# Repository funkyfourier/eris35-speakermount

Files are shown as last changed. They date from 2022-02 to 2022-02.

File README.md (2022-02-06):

# 3D Printable Speaker Wall Mounts for PreSonus ERIS E3.5

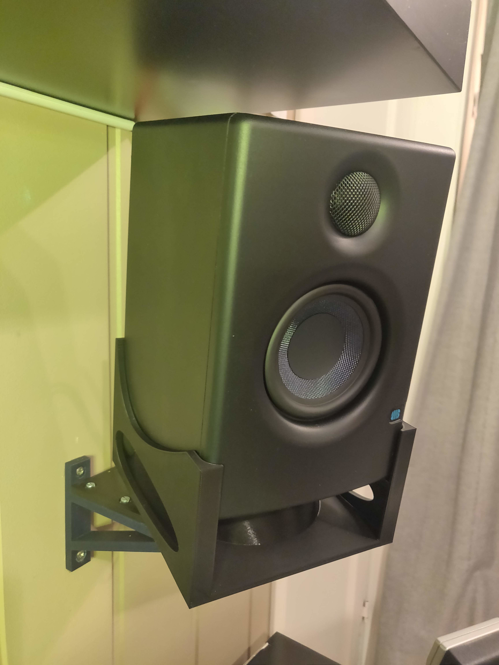
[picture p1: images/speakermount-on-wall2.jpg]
Mounted on wall with speaker


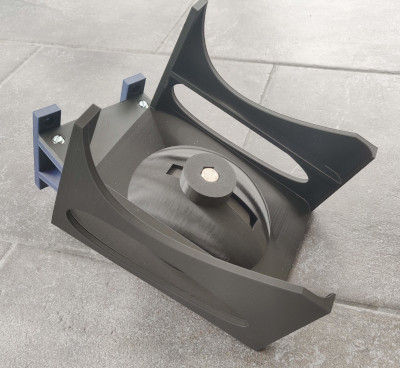
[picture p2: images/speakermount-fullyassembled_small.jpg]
Fully assembled


These are 3D printable speaker wall mounts for [the Presonus ERIS E3.5 speakers](https://www.presonus.com/products/Eris-E35). They can be tiltet and rotated to allow for optimal listening angle. 

The models are made with [FreeCAD](https://www.freecadweb.org/), and all dimensions and sizes should be possible to adjust using the spreadsheet. It may not respond 100% perfect to changes, though, so check the results after editing. Some experience with FreeCAD is recommended.

To build one of them, you will need the following items:

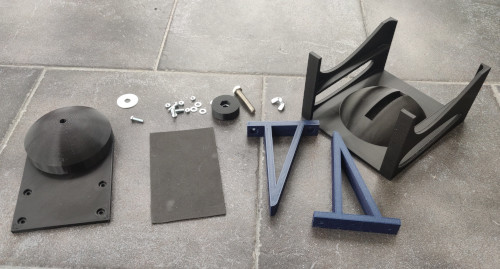
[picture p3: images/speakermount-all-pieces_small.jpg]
All pieces


* Speakerframe.stl
* Bracket.stl
* Fastener.stl
* Shelf.stl
* 4x M4 screws and nuts for mounting shelf to brackets
* 4x ~10mm washers (for M4) for mounting shelf to brackets
* 1x M8 bolted nut
* 1x M8 wing nut
* 1x 30mm washers for the wing nuts
* 2x internal 30mm washers for the fastener (optional)
* screws for mounting brackets to wall
* rubber sheet of some kind (optional)

The rubber sheet is for adding extra friction, and it is placed on top of the dome on the shelf part, with a hole cut in the center.

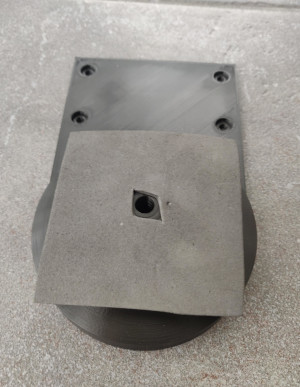
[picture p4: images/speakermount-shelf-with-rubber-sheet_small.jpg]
Rubber sheet


You can probably skip it, but I found that they reduce the need for tightening the wing nut quite a bit. I don't know where to get them, I got mine in the packaging of some product I bought.

If you have a slicer and printer which allows for color changing pauses, you can opt to insert an internal washer in the fastener. 

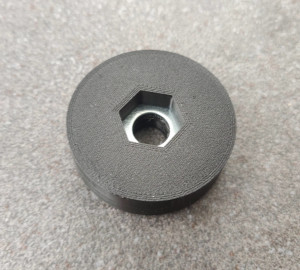
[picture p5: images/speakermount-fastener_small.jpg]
Fastener with internal washer


If you do so, I recommend to add an extra layer on top of the washer to implement sacrifical briding, as explained in [this video by Maker's Muse](https://youtu.be/RPijCjz9G1w?t=117). He does it in CAD, but I just did it directly in Prusa Slicer, although a bit cumbersome. 

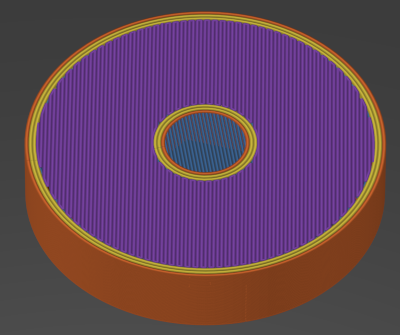
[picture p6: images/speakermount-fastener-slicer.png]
Fastener in slicer with sacrificial support


The speaker frame itself should be printed in this orientation:

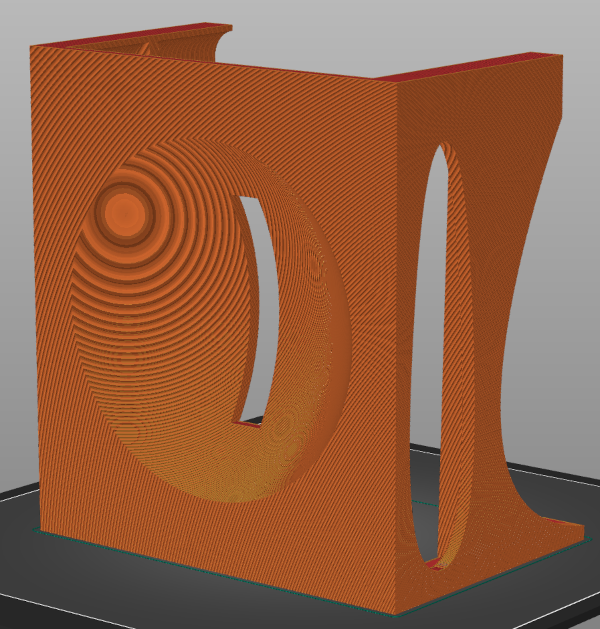
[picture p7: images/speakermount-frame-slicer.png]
Fastener in slicer with sacrificial support


No supports are needed. 

**You may want to do a couple of test prints before printing the frames, since the dimensions might be off depending on how your (and my) printer is set up and tuned.**

The shelves can be printed sideways, also without supports.

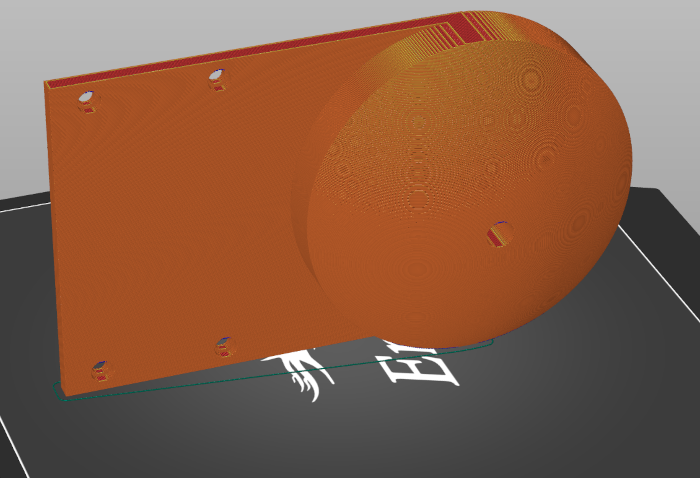
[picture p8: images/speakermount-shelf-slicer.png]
Shelf sideways in slicer


If you know a little bit about [FreeCAD](https://www.freecadweb.org/) you may adjust some of the values in the spreadsheet, like screw hole sizes etc. Also, it is fully possible to adjust the frame for many other speakers, so remix away!

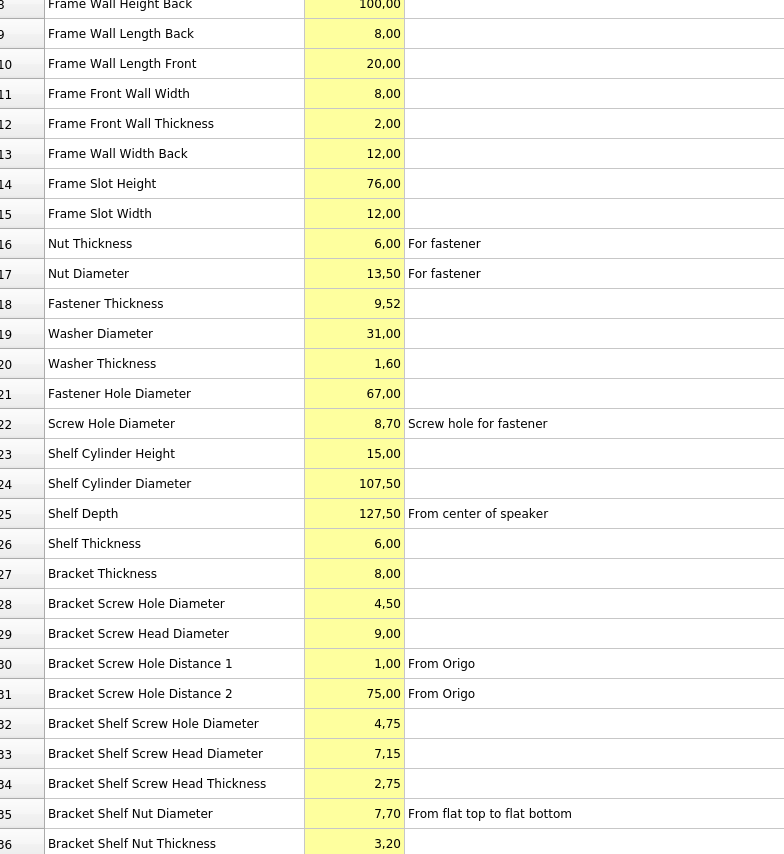
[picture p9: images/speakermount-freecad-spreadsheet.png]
FreeCAD spreadsheet


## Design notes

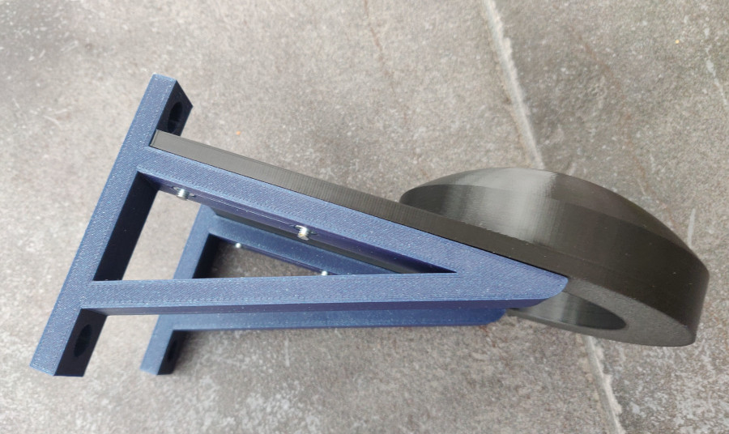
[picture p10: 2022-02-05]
images/speakermount-shelf-and-brackets.jpg

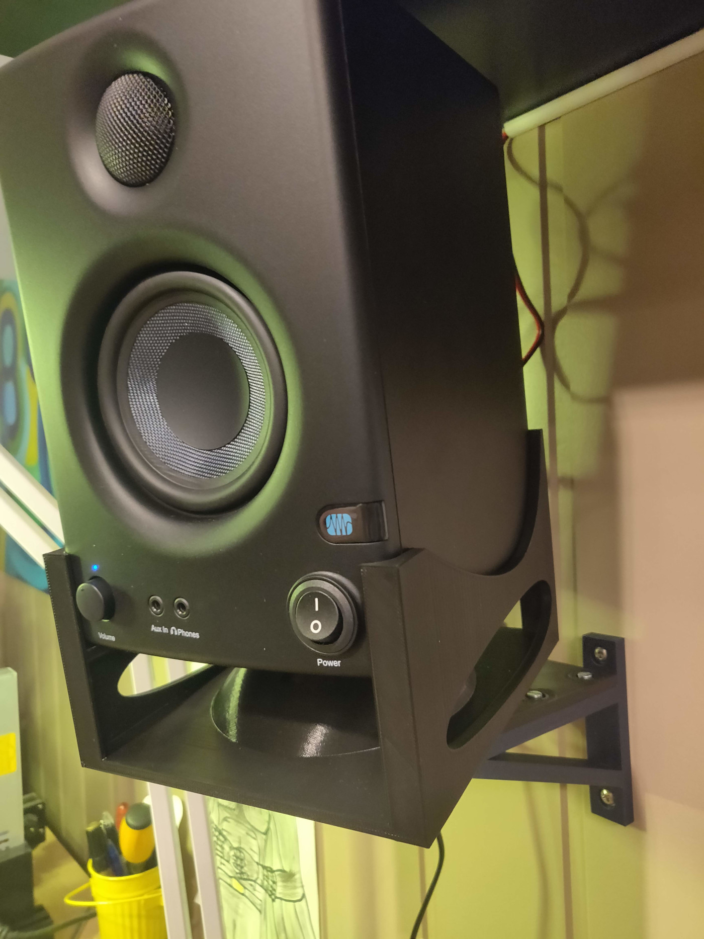
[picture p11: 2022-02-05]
images/speakermount-on-wall.jpg

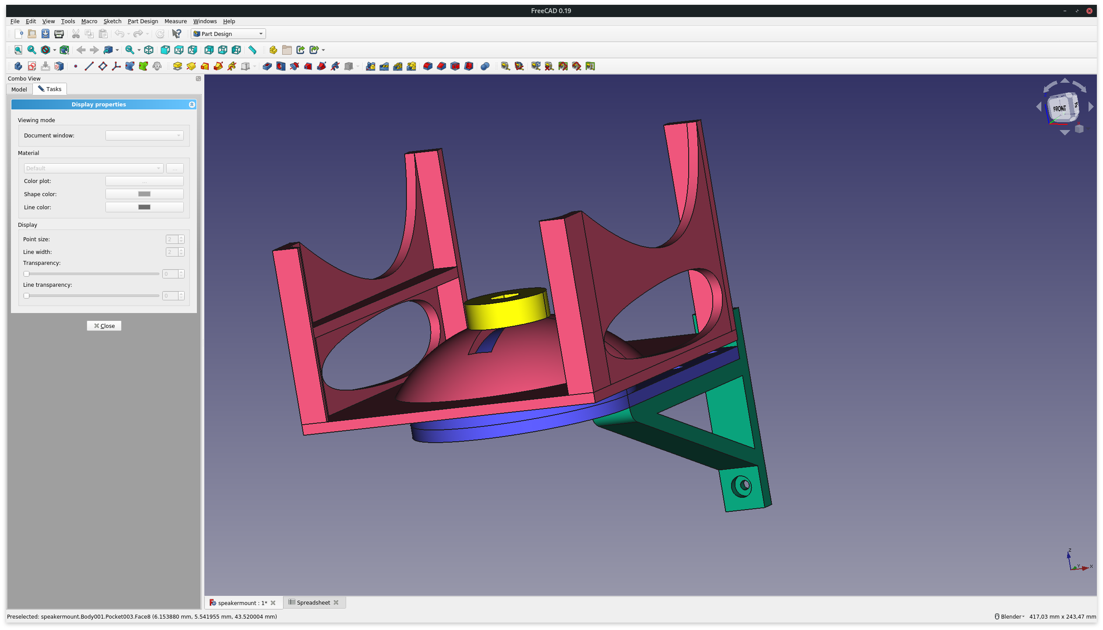
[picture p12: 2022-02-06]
images/freecad.png

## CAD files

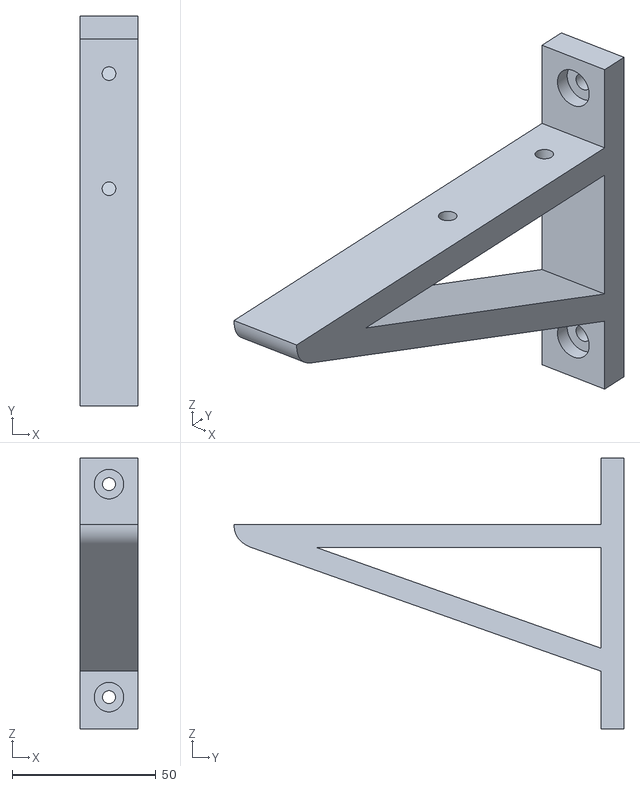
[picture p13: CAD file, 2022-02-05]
Bracket.stl
20.2 x 135.5 x 94.0

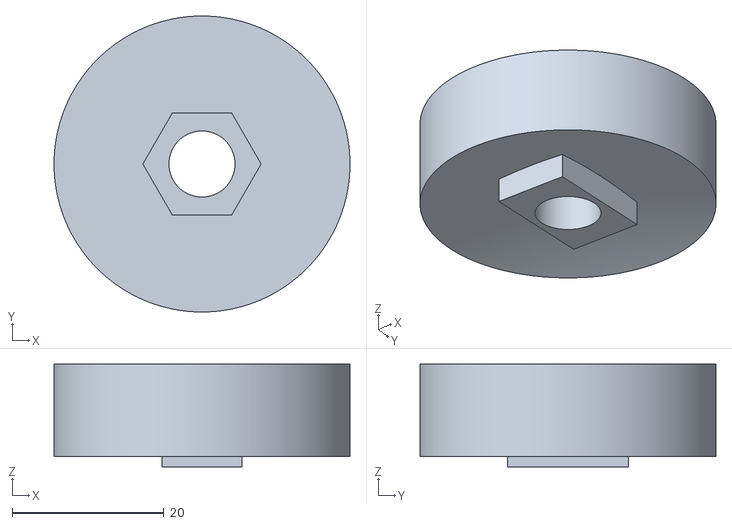
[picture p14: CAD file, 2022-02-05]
Fastener.stl
39.0 x 39.0 x 13.5

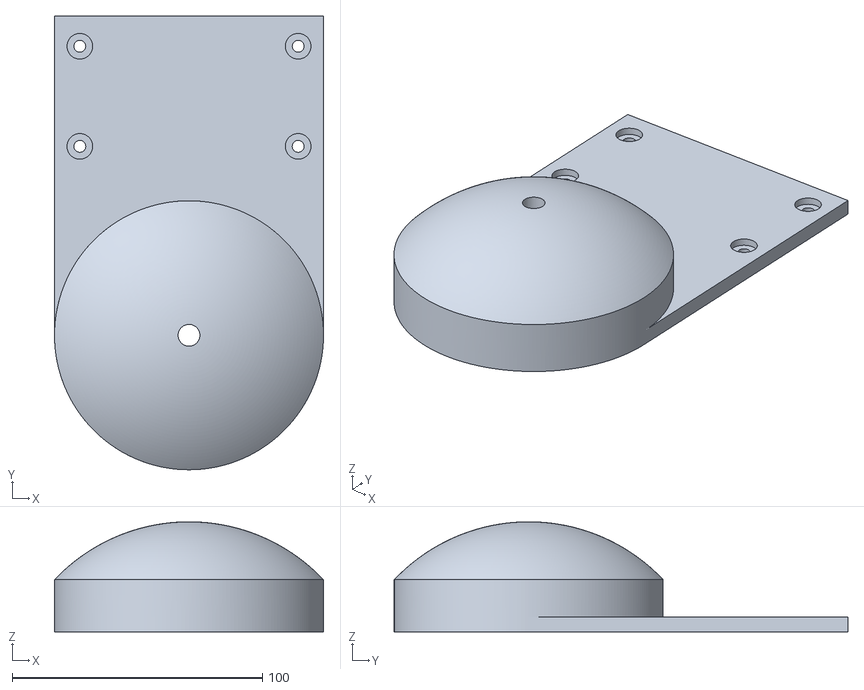
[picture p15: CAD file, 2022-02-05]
Shelf.stl
107.5 x 181.2 x 43.9

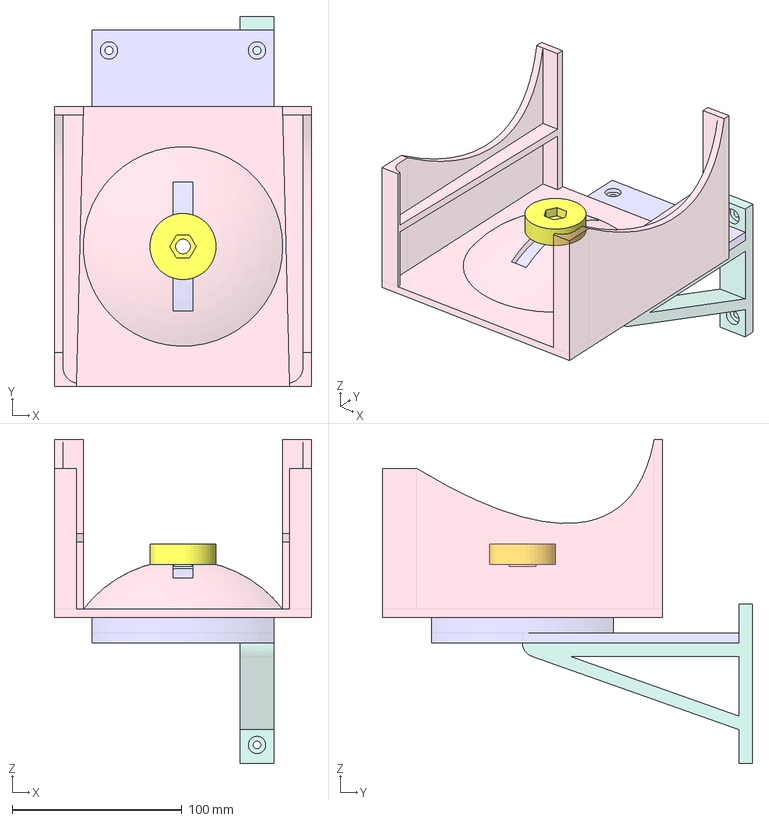
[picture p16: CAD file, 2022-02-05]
speakermount.FCStd
151.5 x 218.0 x 191.0 mm
SpeakerFrame
Fastener
Shelf
Bracket

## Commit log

2022-02-05 Added speaker dimensions
    [speakermount.FCStd]
2022-02-05 Sphere of speaker frame seems to be done
    [speakermount.FCStd]
2022-02-05 Added first back wall
    [speakermount.FCStd]
2022-02-05 Front walls roughly done
    [speakermount.FCStd]
2022-02-05 Frame wall heights in spreadsheet
    [speakermount.FCStd]
2022-02-05 Frame walls seem to be basically done
    [speakermount.FCStd]
2022-02-05 Speaker sills
    [speakermount.FCStd]
2022-02-05 Frame slot
    [speakermount.FCStd]
2022-02-05 Screw hole for fastener
    [speakermount.FCStd]
2022-02-05 Added rotation stopper to fastener
    [speakermount.FCStd]
2022-02-05 Bracket done apart from wall mount
    [speakermount.FCStd]
2022-02-05 Screw hole for tightener
    [speakermount.FCStd]
2022-02-05 Basic wall mount
    [speakermount.FCStd]
2022-02-05 Rudimentary wall mount toughening
    [speakermount.FCStd]
2022-02-05 Thinned wall and bottom thickness
    [speakermount.FCStd]
2022-02-05 Readjusted thicknesses
    [speakermount.FCStd]
2022-02-05 Removed wall mount
    [speakermount.FCStd]
2022-02-05 Adjusted rotation stopper
    [speakermount.FCStd]
2022-02-05 Adjusted fastener thickness
    [speakermount.FCStd]
2022-02-05 Renamed bracket to shelf
    [speakermount.FCStd]
2022-02-05 Bracket seems to be good
    [speakermount.FCStd]
2022-02-05 Bracket tuning
    [speakermount.FCStd]
2022-02-05 Bracket screw holes
    [speakermount.FCStd]
2022-02-05 Bracket nut holes
    [speakermount.FCStd]
2022-02-05 Screw holes for shelf/bracket done
    [speakermount.FCStd]
2022-02-05 Bracket wall screw holes
    [speakermount.FCStd]
2022-02-05 Mirrored screw holes on shelf
    [speakermount.FCStd]
2022-02-05 Made tightener hole a little less deep
    [speakermount.FCStd]
2022-02-05 Fastener radius is not dependant on slot height anymore, but correctly on washer diameter
    [speakermount.FCStd]
2022-02-05 Some adjustments here and there
    [speakermount.FCStd]
2022-02-05 More space behind speaker
    [speakermount.FCStd]
2022-02-05 Nicer seem on back and side walls
    [speakermount.FCStd]
2022-02-05 Some measuring adjustments after test prints
    [speakermount.FCStd]
2022-02-05 First frame test prints
    [speakermount.FCStd]
2022-02-05 First real print of shelf
    [speakermount.FCStd]
2022-02-05 Side holes
    [speakermount.FCStd]
2022-02-05 Made bracket wider and made space for washers in all screw head holes
    [speakermount.FCStd]
2022-02-05 Made all parts visible
    [speakermount.FCStd]
2022-02-05 Added STL files
    [Bracket.stl, Fastener.stl, Shelf.stl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]
2022-02-05 Frame print orientation
